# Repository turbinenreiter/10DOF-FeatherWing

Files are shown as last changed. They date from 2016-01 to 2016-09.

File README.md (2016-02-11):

# 10DOF-FeatherWing

This is a daughter-board for Adafruits Feather boards.  

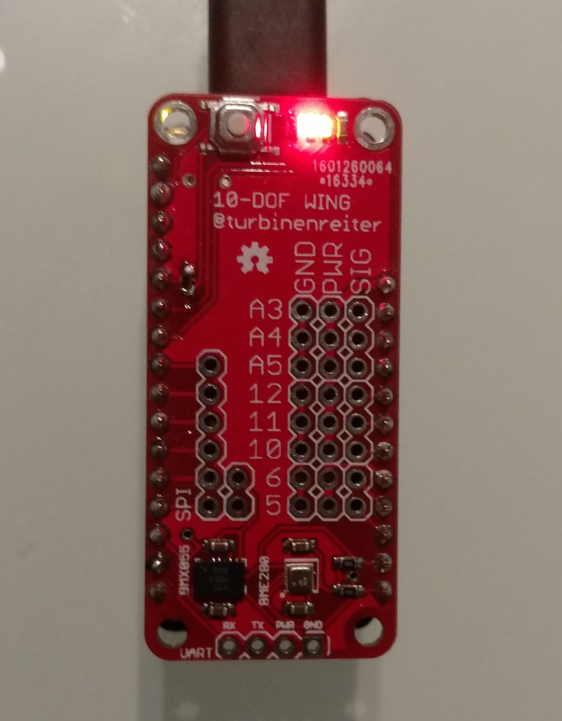
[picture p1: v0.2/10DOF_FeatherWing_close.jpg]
10DOF-FeatherWing


It features:
  * 3-axis accelerometer
  * 3-axis gyroscope
  * 3-axis magnetometer
  * temperature sensor
  * pressure sensor
  * humidity sensor
  * 8 servo headers (PWR from BAT)
  * SPI header
  * UART header
  * one green and one red LED
  * one switch
  * GPIO#9 (A7) is connected to BAT to measure it's voltage

The board has been produced and tested.
  * all sensors work
  * red LED works
  * green LED is on when connected to USB, but not battery - no idea why

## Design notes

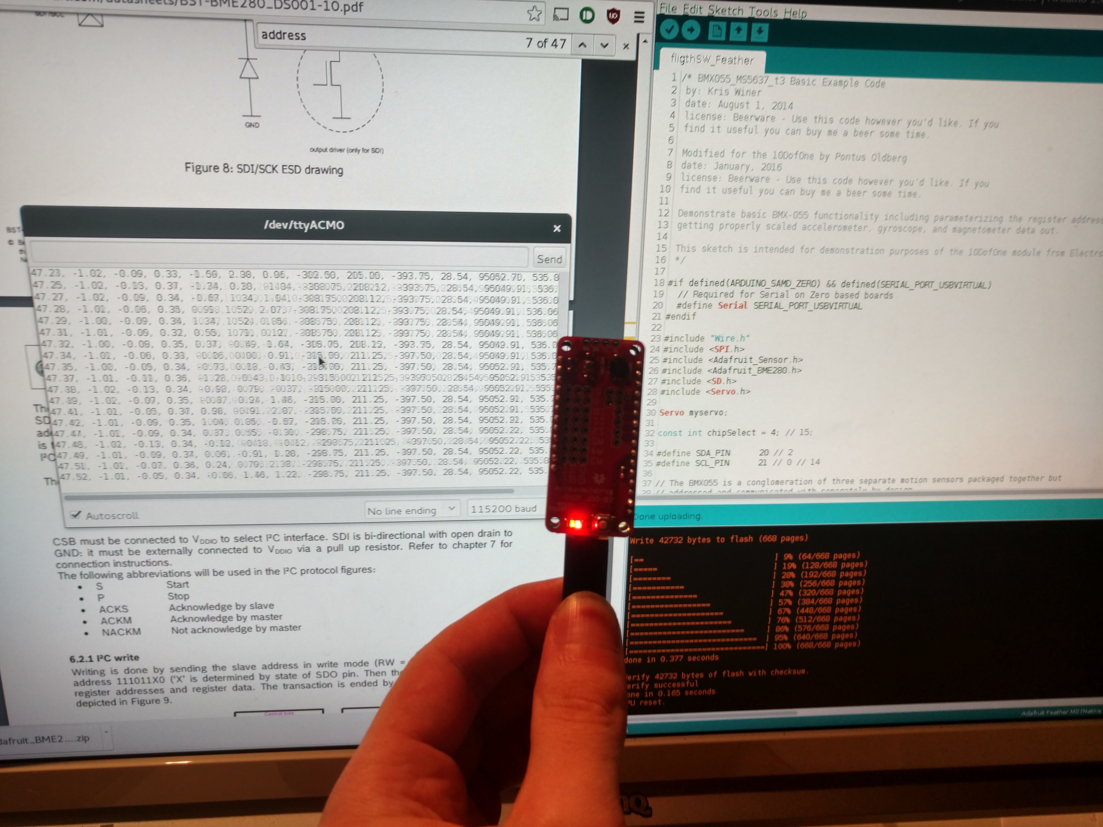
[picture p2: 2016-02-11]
v0.2/10DOF_FeatherWing_running.jpg

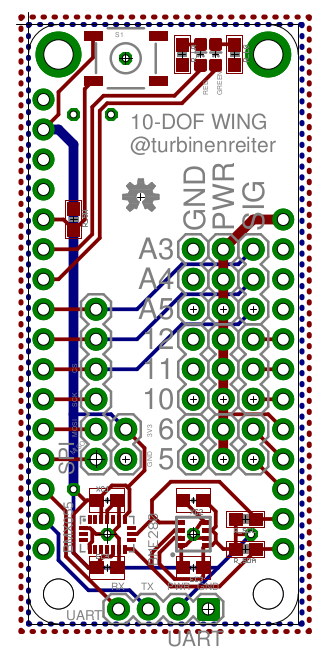
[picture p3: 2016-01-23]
v0.2/10DOF_FeatherWing_brd.png

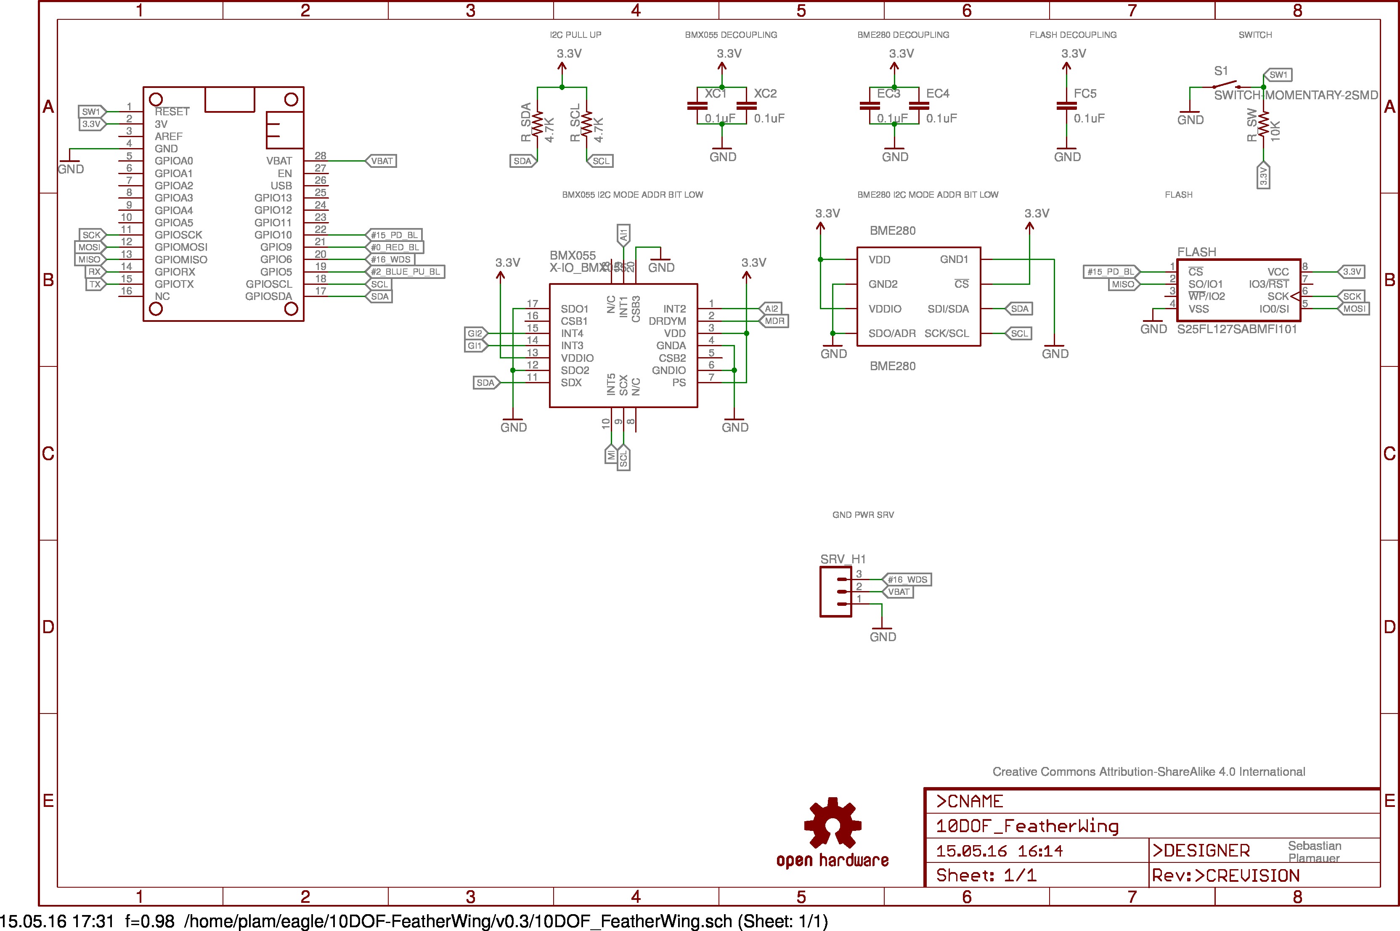
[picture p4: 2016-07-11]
v0.4SENSE/sch.jpg

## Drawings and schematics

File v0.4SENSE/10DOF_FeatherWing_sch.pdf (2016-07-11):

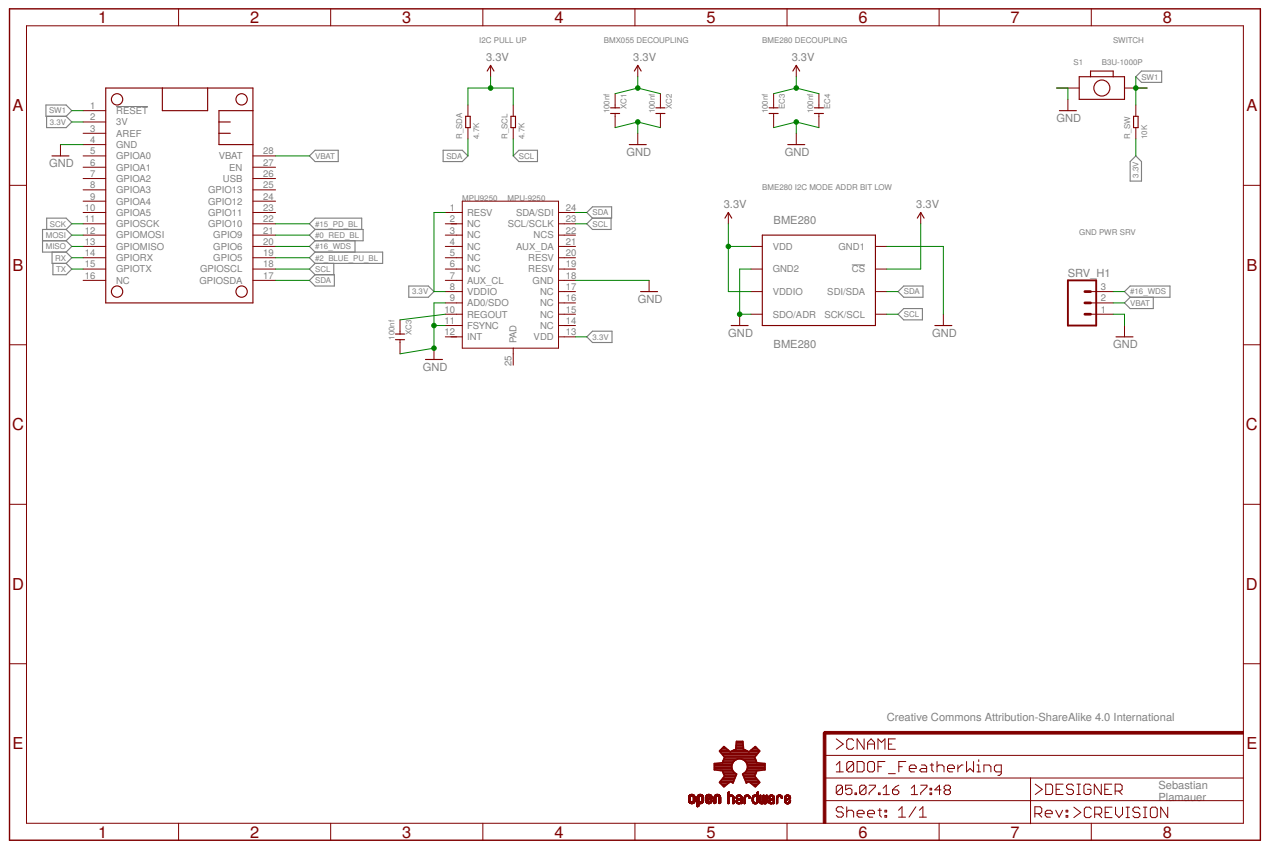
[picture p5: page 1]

BME280 I2C MODE ADDR BIT LOW

Creative Commons Attribution-ShareAlike 4.0 International

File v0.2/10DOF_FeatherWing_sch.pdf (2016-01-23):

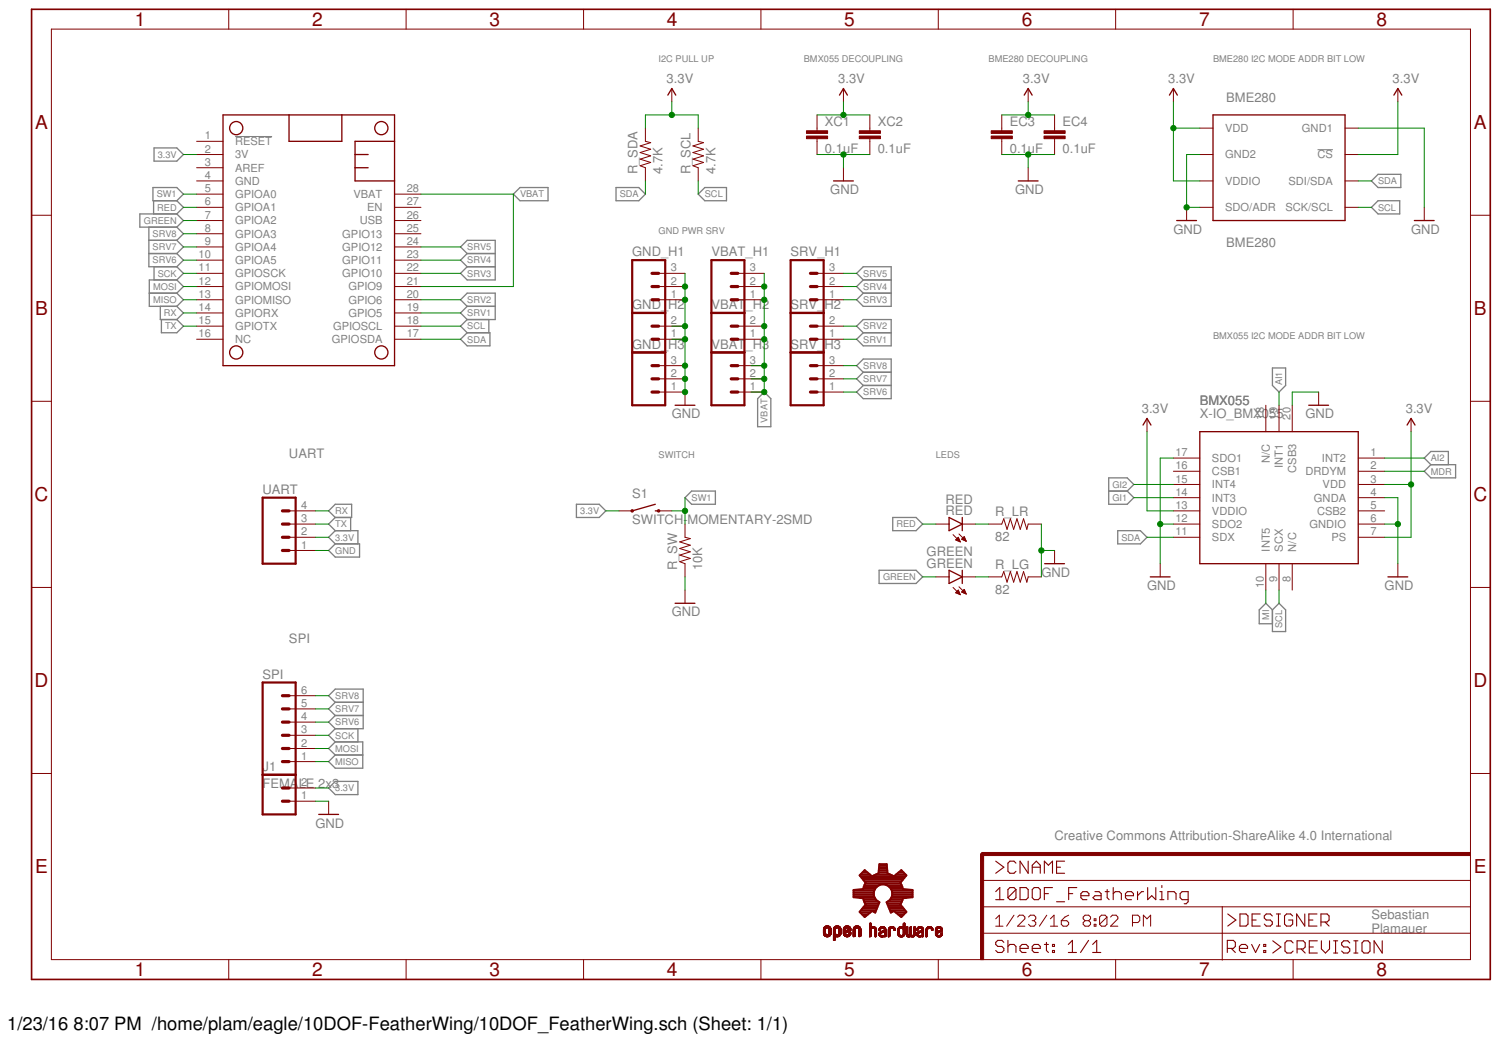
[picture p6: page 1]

BMX055 I2C MODE ADDR BIT LOW

Creative Commons Attribution-ShareAlike 4.0 International

1/23/16 8:07 PM /home/plam/eagle/10DOF-FeatherWing/10DOF_FeatherWing.sch (Sheet: 1/1)

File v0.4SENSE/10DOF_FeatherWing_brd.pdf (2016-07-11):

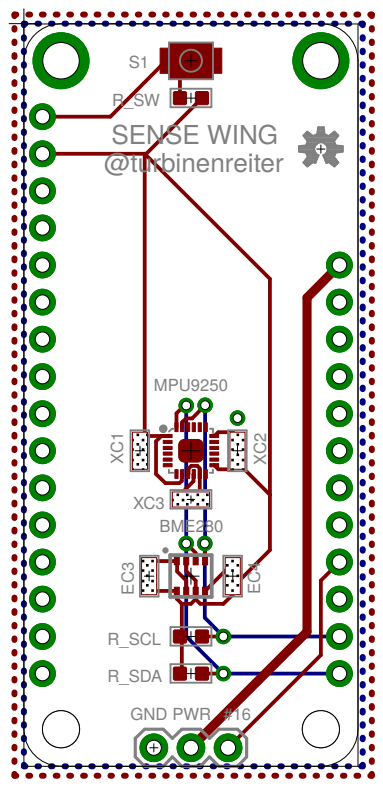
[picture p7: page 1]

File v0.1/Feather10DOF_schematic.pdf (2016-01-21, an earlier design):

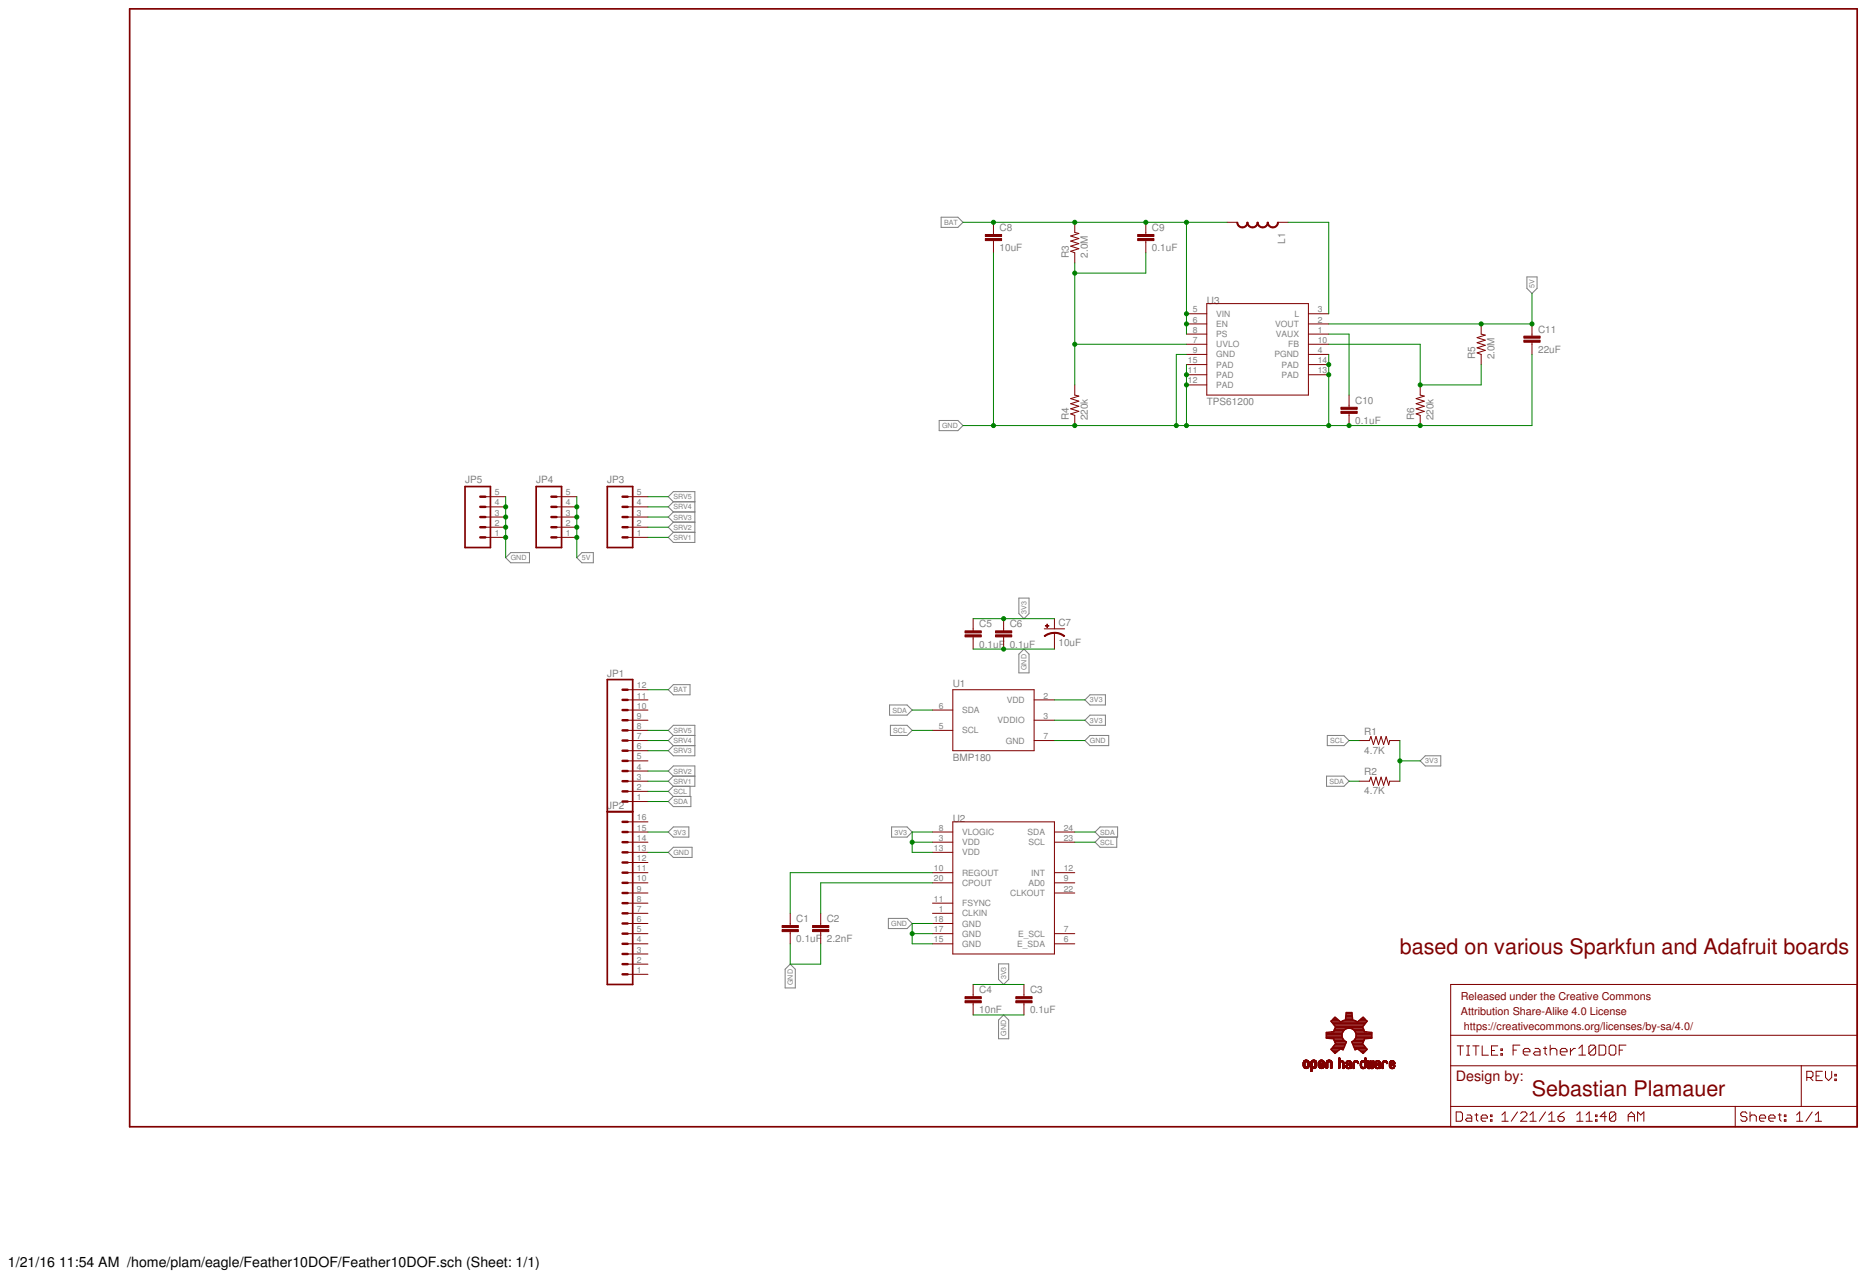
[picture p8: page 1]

based on various Sparkfun and Adafruit boards

Released under the Creative Commons Attribution Share-Alike 4.0 License

https://creativecommons.org/licenses/by-sa/4.0/

1/21/16 11:54 AM /home/plam/eagle/Feather10DOF/Feather10DOF.sch (Sheet: 1/1)

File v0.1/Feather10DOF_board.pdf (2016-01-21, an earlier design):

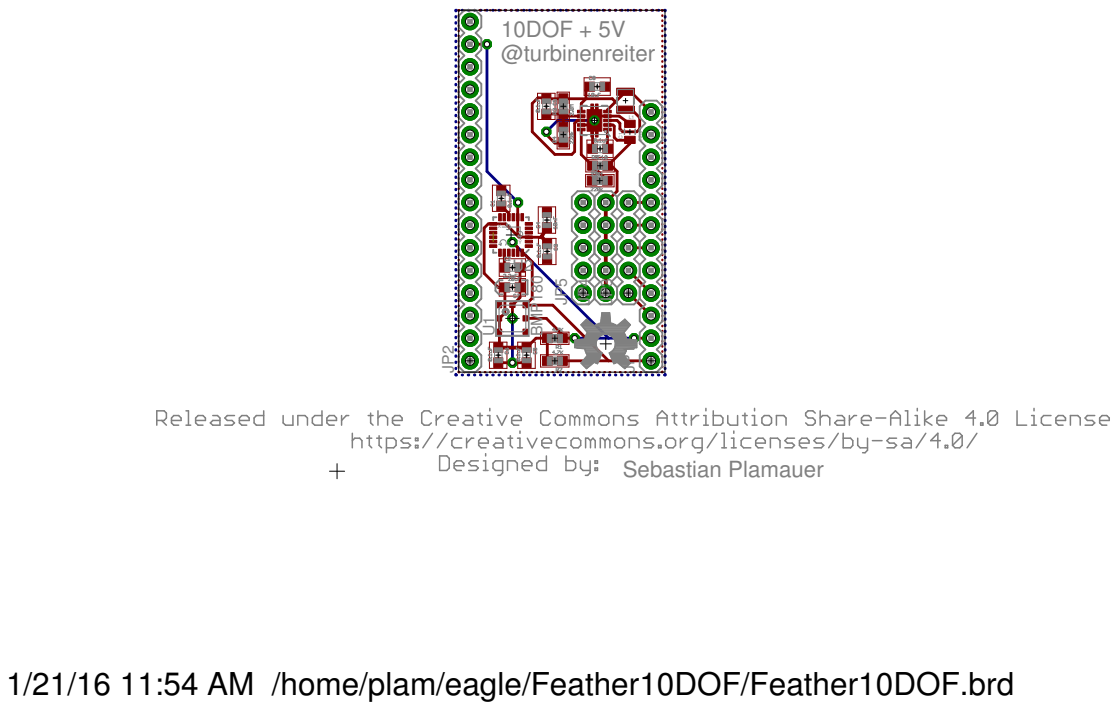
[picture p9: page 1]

1/21/16 11:54 AM /home/plam/eagle/Feather10DOF/Feather10DOF.brd

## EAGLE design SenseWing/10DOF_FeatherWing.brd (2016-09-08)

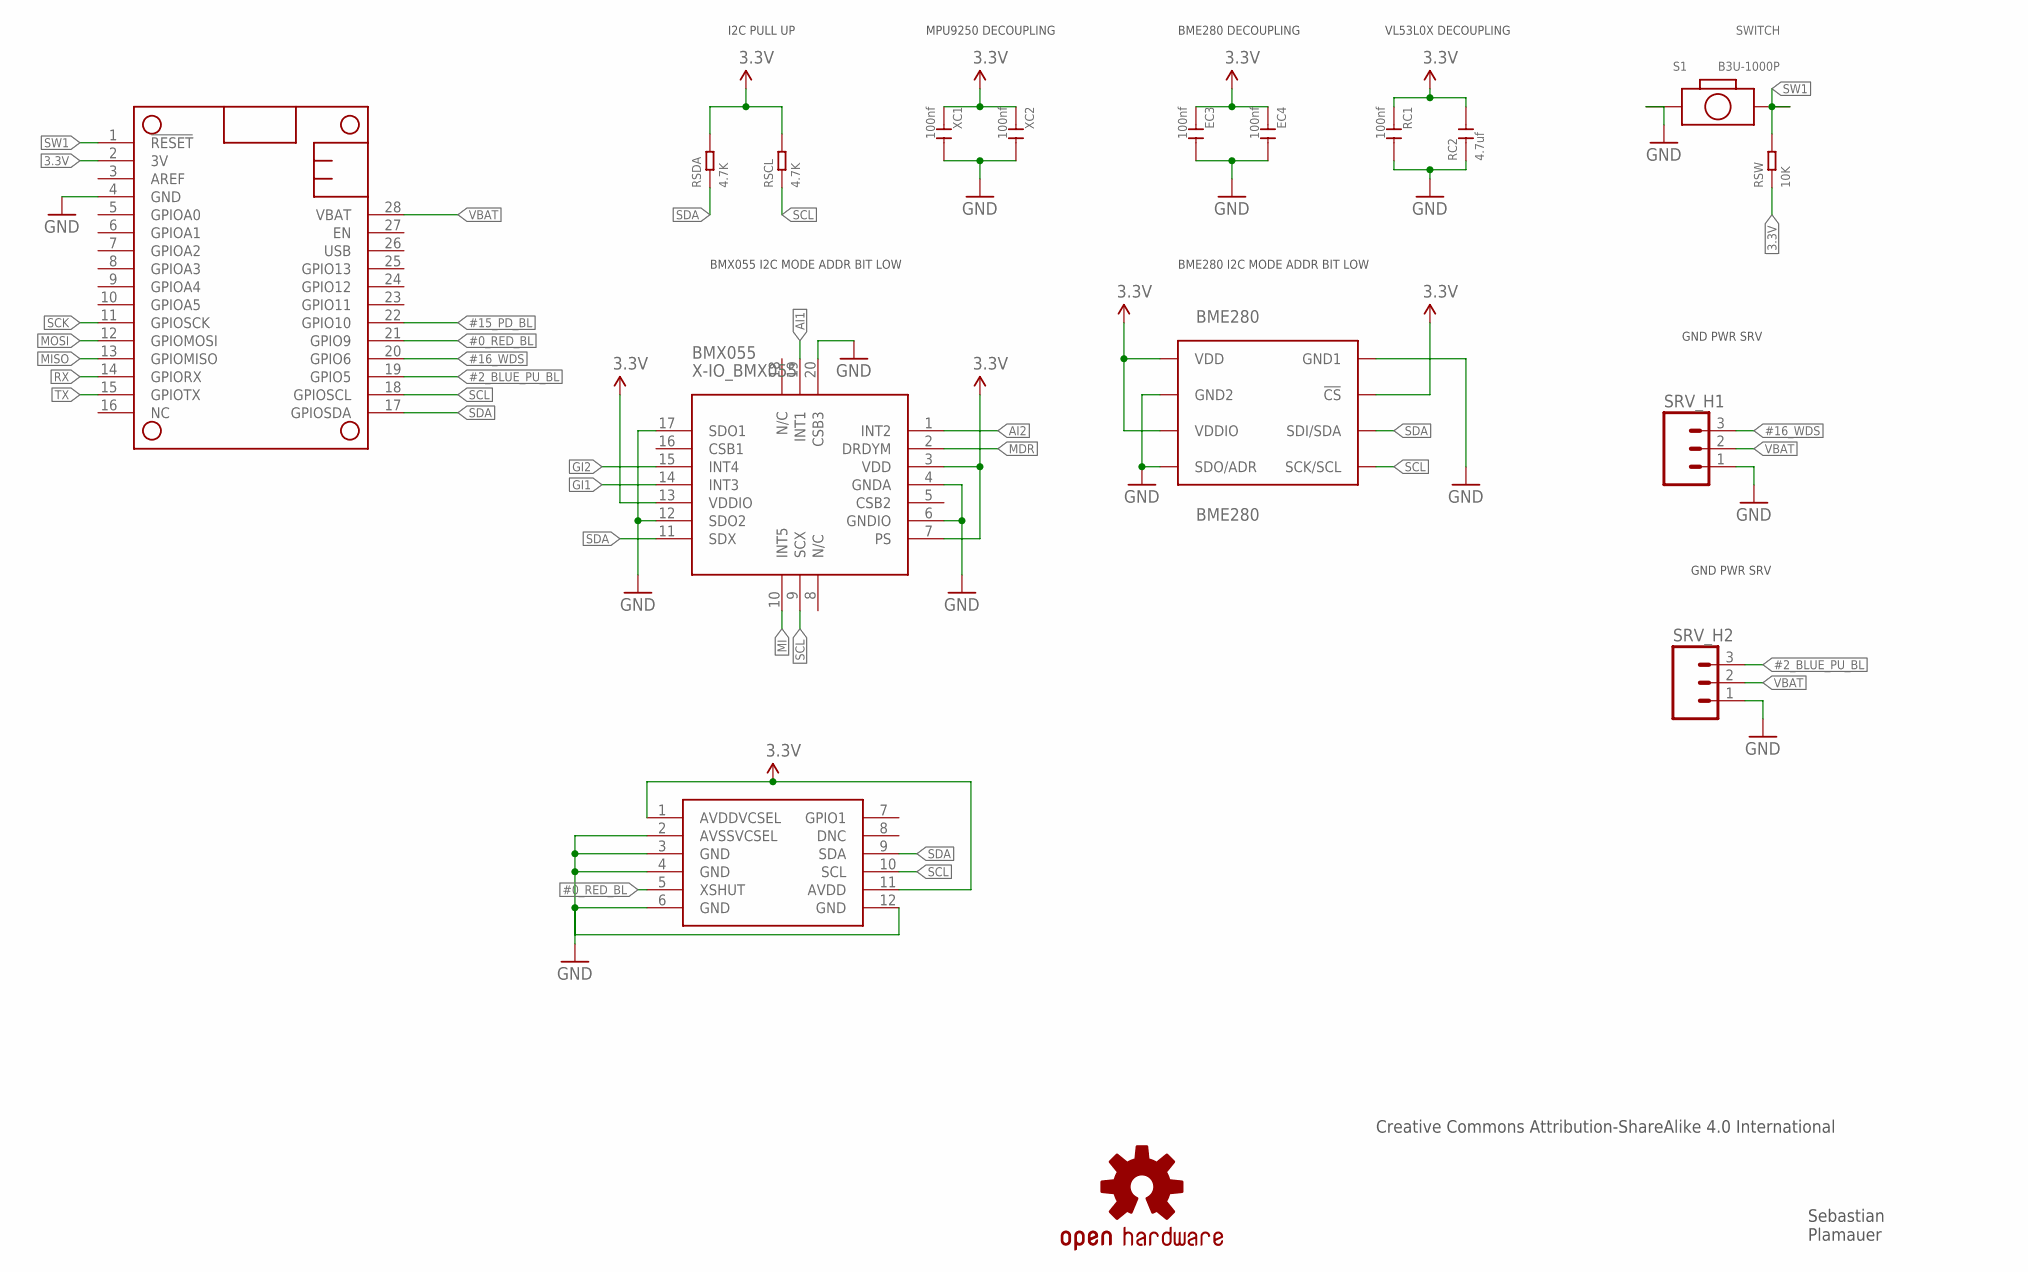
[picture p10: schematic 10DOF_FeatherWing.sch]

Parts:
BME280: BME280; BME280COMPONENTLIBRARY_BME280_LGA
BMX055: X-IO_BMX055
EC3, EC4: 100nf; C0603
LOGO1: OSHW-LOGOS; OSHW-LOGO-S
MS1: FEATHERWING
RC1: 100nf; C0603
RC2: 4.7uf; C0603
RSCL: 4.7K; R0603
RSDA: 4.7K; R0603
RSW: 10K; R0603
S1: B3U-1000P; SW2-SMD-3.0X2.5X1.2+0.4MM
SRV_H1, SRV_H2: M03PTH; 1X03
U$1: VL53L0X
XC1, XC2: 100nf; C0603

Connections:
3.3V: BME280.P$2 (!CS), BME280.P$6 (VDDIO), BME280.P$8 (VDD), BMX055.3 (VDD), BMX055.7 (PS), BMX055.13 (VDDIO), EC3.1, EC4.1, MS1.2 (3V), RC1.1, RC2.2, RSCL.2, RSDA.2, RSW.1, U$1.1 (AVDDVCSEL), U$1.11 (AVDD), XC1.1, XC2.1
#0_RED_BL: MS1.21 (GPIO9), U$1.5 (XSHUT)
#2_BLUE_PU_BL: MS1.19 (GPIO5), SRV_H2.3
#15_PD_BL: MS1.22 (GPIO10)
#16_WDS: MS1.20 (GPIO6), SRV_H1.3
AI1: BMX055.19 (INT1)
AI2: BMX055.1 (INT2)
GI1: BMX055.14 (INT3)
GI2: BMX055.15 (INT4)
GND: BME280.P$1 (GND1), BME280.P$5 (SDO/ADR), BME280.P$7 (GND2), BMX055.4 (GNDA), BMX055.6 (GNDIO), BMX055.12 (SDO2), BMX055.17 (SDO1), BMX055.20 (CSB3), EC3.2, EC4.2, MS1.4 (GND), RC1.2, RC2.1, S1.1, SRV_H1.1, SRV_H2.1, U$1.2 (AVSSVCSEL), U$1.3 (GND), U$1.4 (GND), U$1.6 (GND), U$1.12 (GND), XC1.2, XC2.2
MDR: BMX055.2 (DRDYM)
MI: BMX055.10 (INT5)
MISO: MS1.13 (GPIOMISO)
MOSI: MS1.12 (GPIOMOSI)
RX: MS1.14 (GPIORX)
SCK: MS1.11 (GPIOSCK)
SCL: BME280.P$4 (SCK/SCL), BMX055.9 (SCX), MS1.18 (GPIOSCL), RSCL.1, U$1.10 (SCL)
SDA: BME280.P$3 (SDI/SDA), BMX055.11 (SDX), MS1.17 (GPIOSDA), RSDA.1, U$1.9 (SDA)
SW1: MS1.1 (!RESET), RSW.2, S1.2
TX: MS1.15 (GPIOTX)
VBAT: MS1.28 (VBAT), SRV_H1.2, SRV_H2.2

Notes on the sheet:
I2C PULL UP
MPU9250 DECOUPLING
BME280 DECOUPLING
BME280 I2C MODE ADDR BIT LOW
GND PWR SRV
SWITCH
Sebastian Plamauer
Creative Commons Attribution-ShareAlike 4.0 International
VL53L0X DECOUPLING
BMX055 I2C MODE ADDR BIT LOW

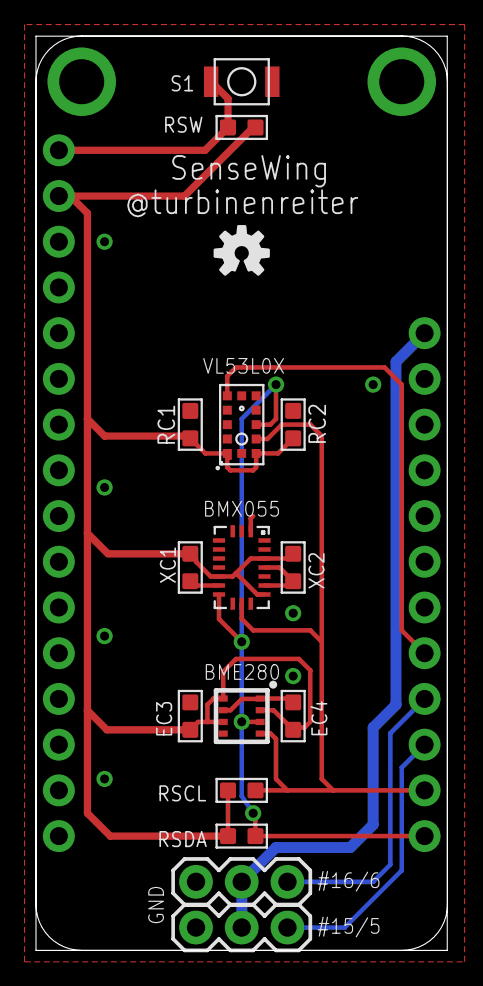
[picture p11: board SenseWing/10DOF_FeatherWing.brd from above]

Board: 2 copper layers, 22.9 x 50.8 mm, 17 parts (0 on the bottom side), 9 nets.

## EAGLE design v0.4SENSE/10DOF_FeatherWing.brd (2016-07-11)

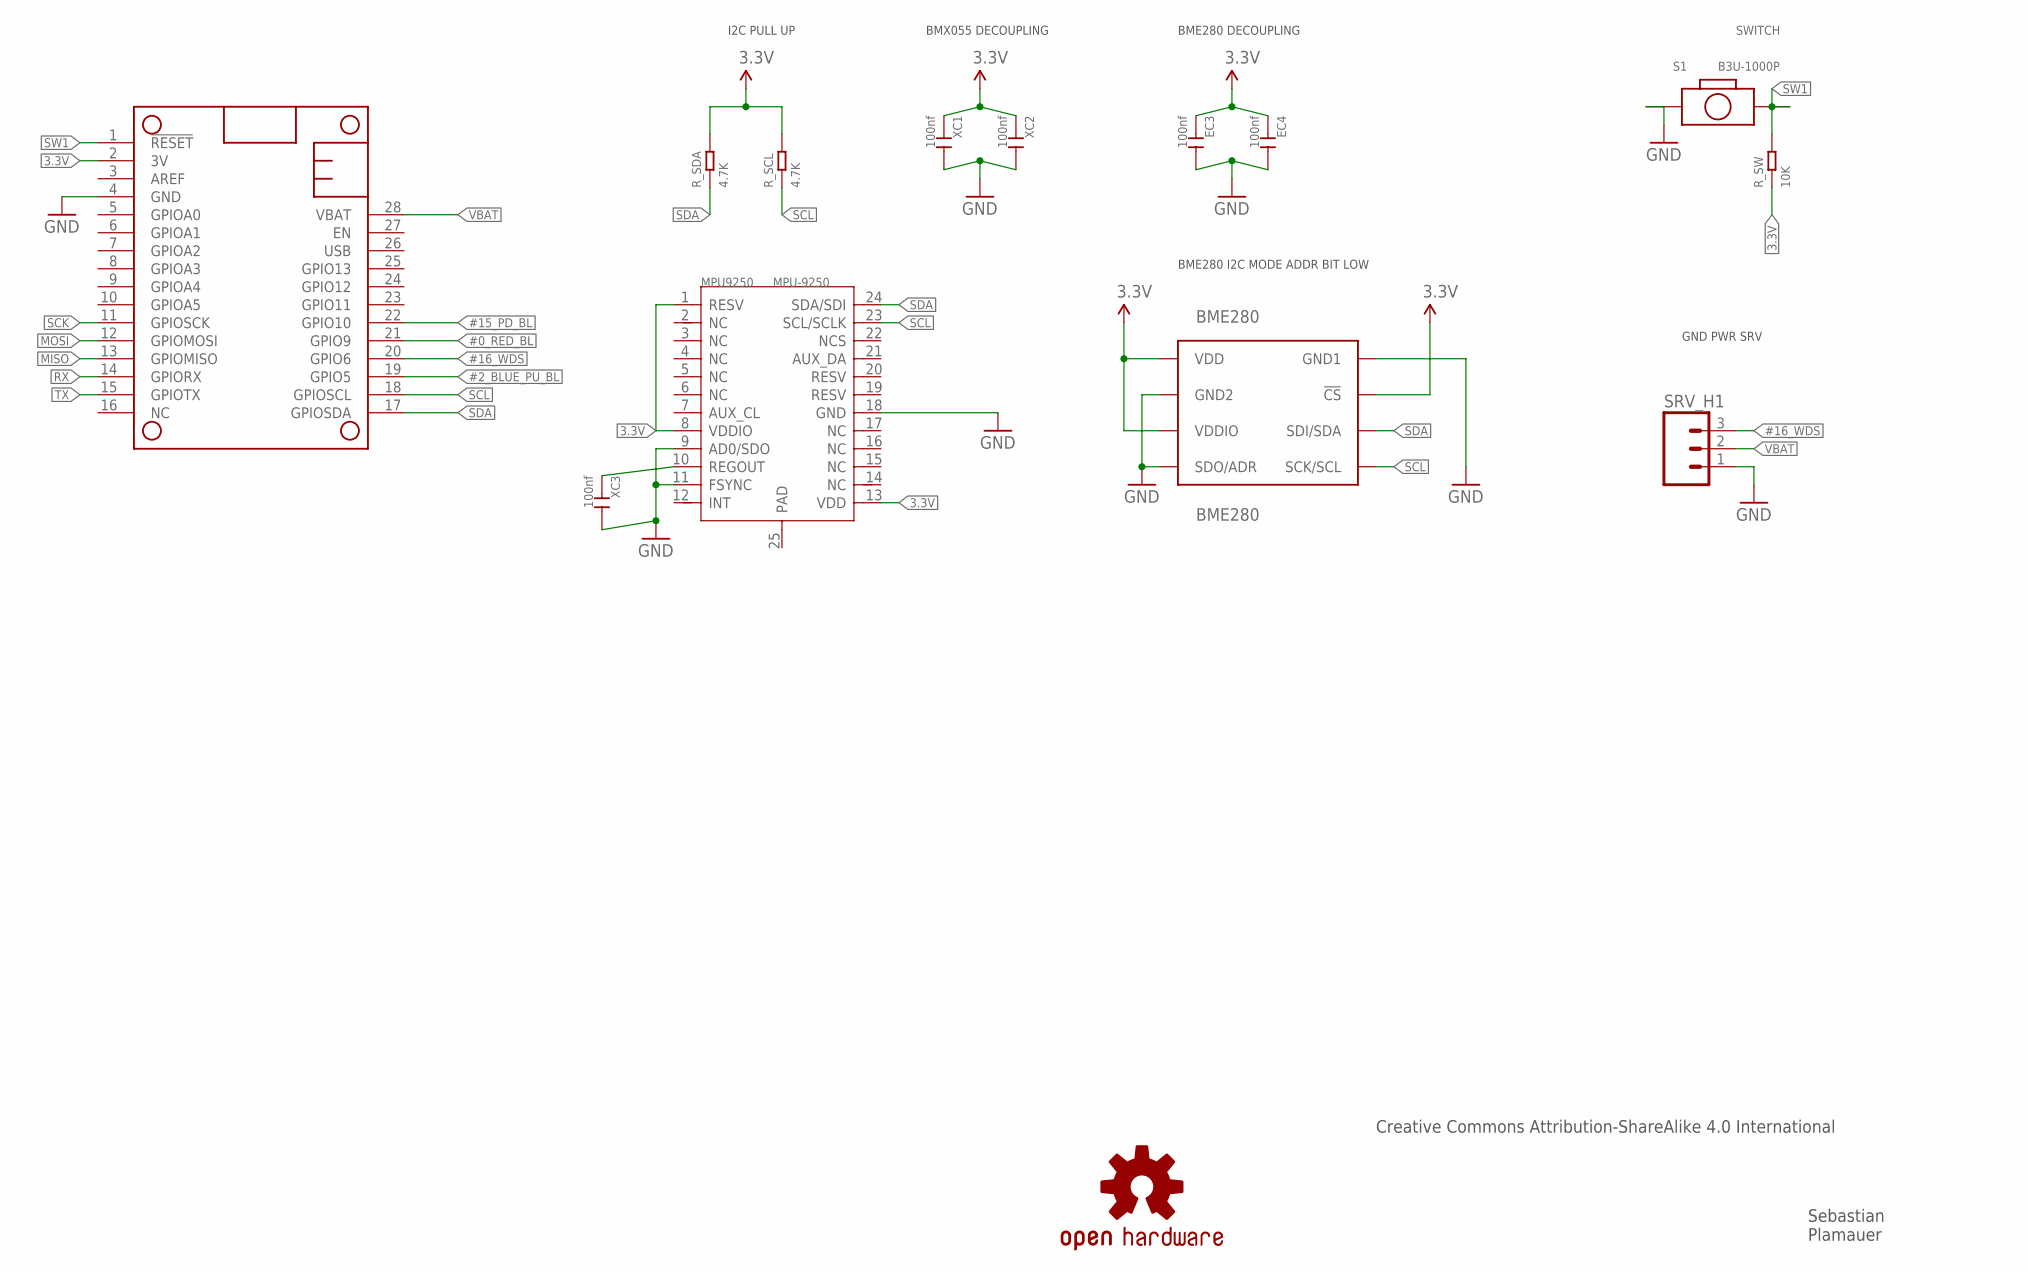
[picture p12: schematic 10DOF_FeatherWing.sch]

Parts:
BME280: BME280; BME280COMPONENTLIBRARY_BME280_LGA
EC3, EC4: 100nf; C0603
LOGO1: OSHW-LOGOS; OSHW-LOGO-S
MPU9250: MPU-9250; QFN24G-0.4-3X3MM
MS1: FEATHERWING
R_SCL: 4.7K; R0603
R_SDA: 4.7K; R0603
R_SW: 10K; R0603
S1: B3U-1000P; SW2-SMD-3.0X2.5X1.2+0.4MM
SRV_H1: M03PTH; 1X03
XC1, XC2, XC3: 100nf; C0603

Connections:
3.3V: BME280.P$2 (!CS), BME280.P$6 (VDDIO), BME280.P$8 (VDD), EC3.1, EC4.1, MPU9250.1 (RESV), MPU9250.8 (VDDIO), MPU9250.13 (VDD), MS1.2 (3V), R_SCL.2, R_SDA.2, R_SW.1, XC1.1, XC2.1
#0_RED_BL: MS1.21 (GPIO9)
#2_BLUE_PU_BL: MS1.19 (GPIO5)
#15_PD_BL: MS1.22 (GPIO10)
#16_WDS: MS1.20 (GPIO6), SRV_H1.3
GND: BME280.P$1 (GND1), BME280.P$5 (SDO/ADR), BME280.P$7 (GND2), EC3.2, EC4.2, MPU9250.9 (AD0/SDO), MPU9250.11 (FSYNC), MPU9250.18 (GND), MS1.4 (GND), S1.1, SRV_H1.1, XC1.2, XC2.2, XC3.2
MISO: MS1.13 (GPIOMISO)
MOSI: MS1.12 (GPIOMOSI)
unnamed: MPU9250.10 (REGOUT), XC3.1
RX: MS1.14 (GPIORX)
SCK: MS1.11 (GPIOSCK)
SCL: BME280.P$4 (SCK/SCL), MPU9250.23 (SCL/SCLK), MS1.18 (GPIOSCL), R_SCL.1
SDA: BME280.P$3 (SDI/SDA), MPU9250.24 (SDA/SDI), MS1.17 (GPIOSDA), R_SDA.1
SW1: MS1.1 (!RESET), R_SW.2, S1.2
TX: MS1.15 (GPIOTX)
VBAT: MS1.28 (VBAT), SRV_H1.2

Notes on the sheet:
I2C PULL UP
BMX055 DECOUPLING
BME280 DECOUPLING
BME280 I2C MODE ADDR BIT LOW
GND PWR SRV
SWITCH
Sebastian Plamauer
Creative Commons Attribution-ShareAlike 4.0 International

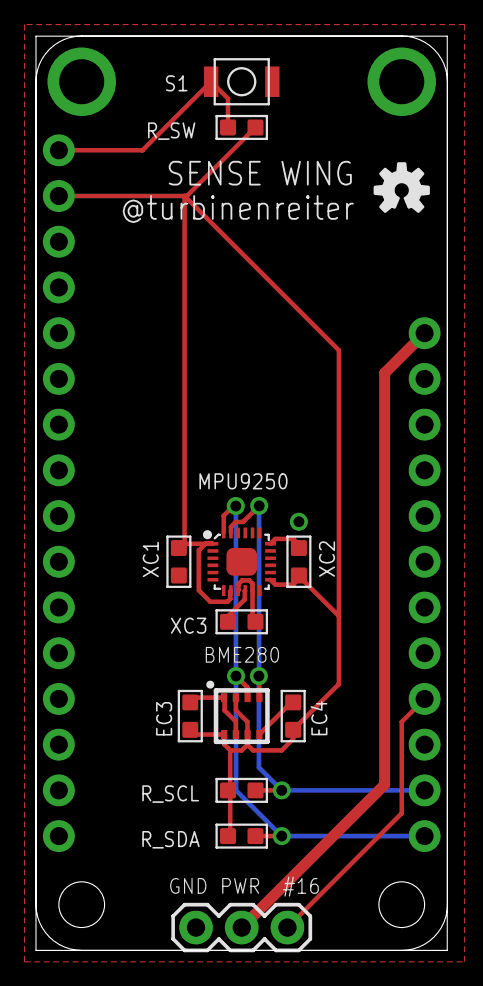
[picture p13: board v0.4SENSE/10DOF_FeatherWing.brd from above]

Board: 2 copper layers, 22.9 x 50.8 mm, 14 parts (0 on the bottom side), 8 nets.

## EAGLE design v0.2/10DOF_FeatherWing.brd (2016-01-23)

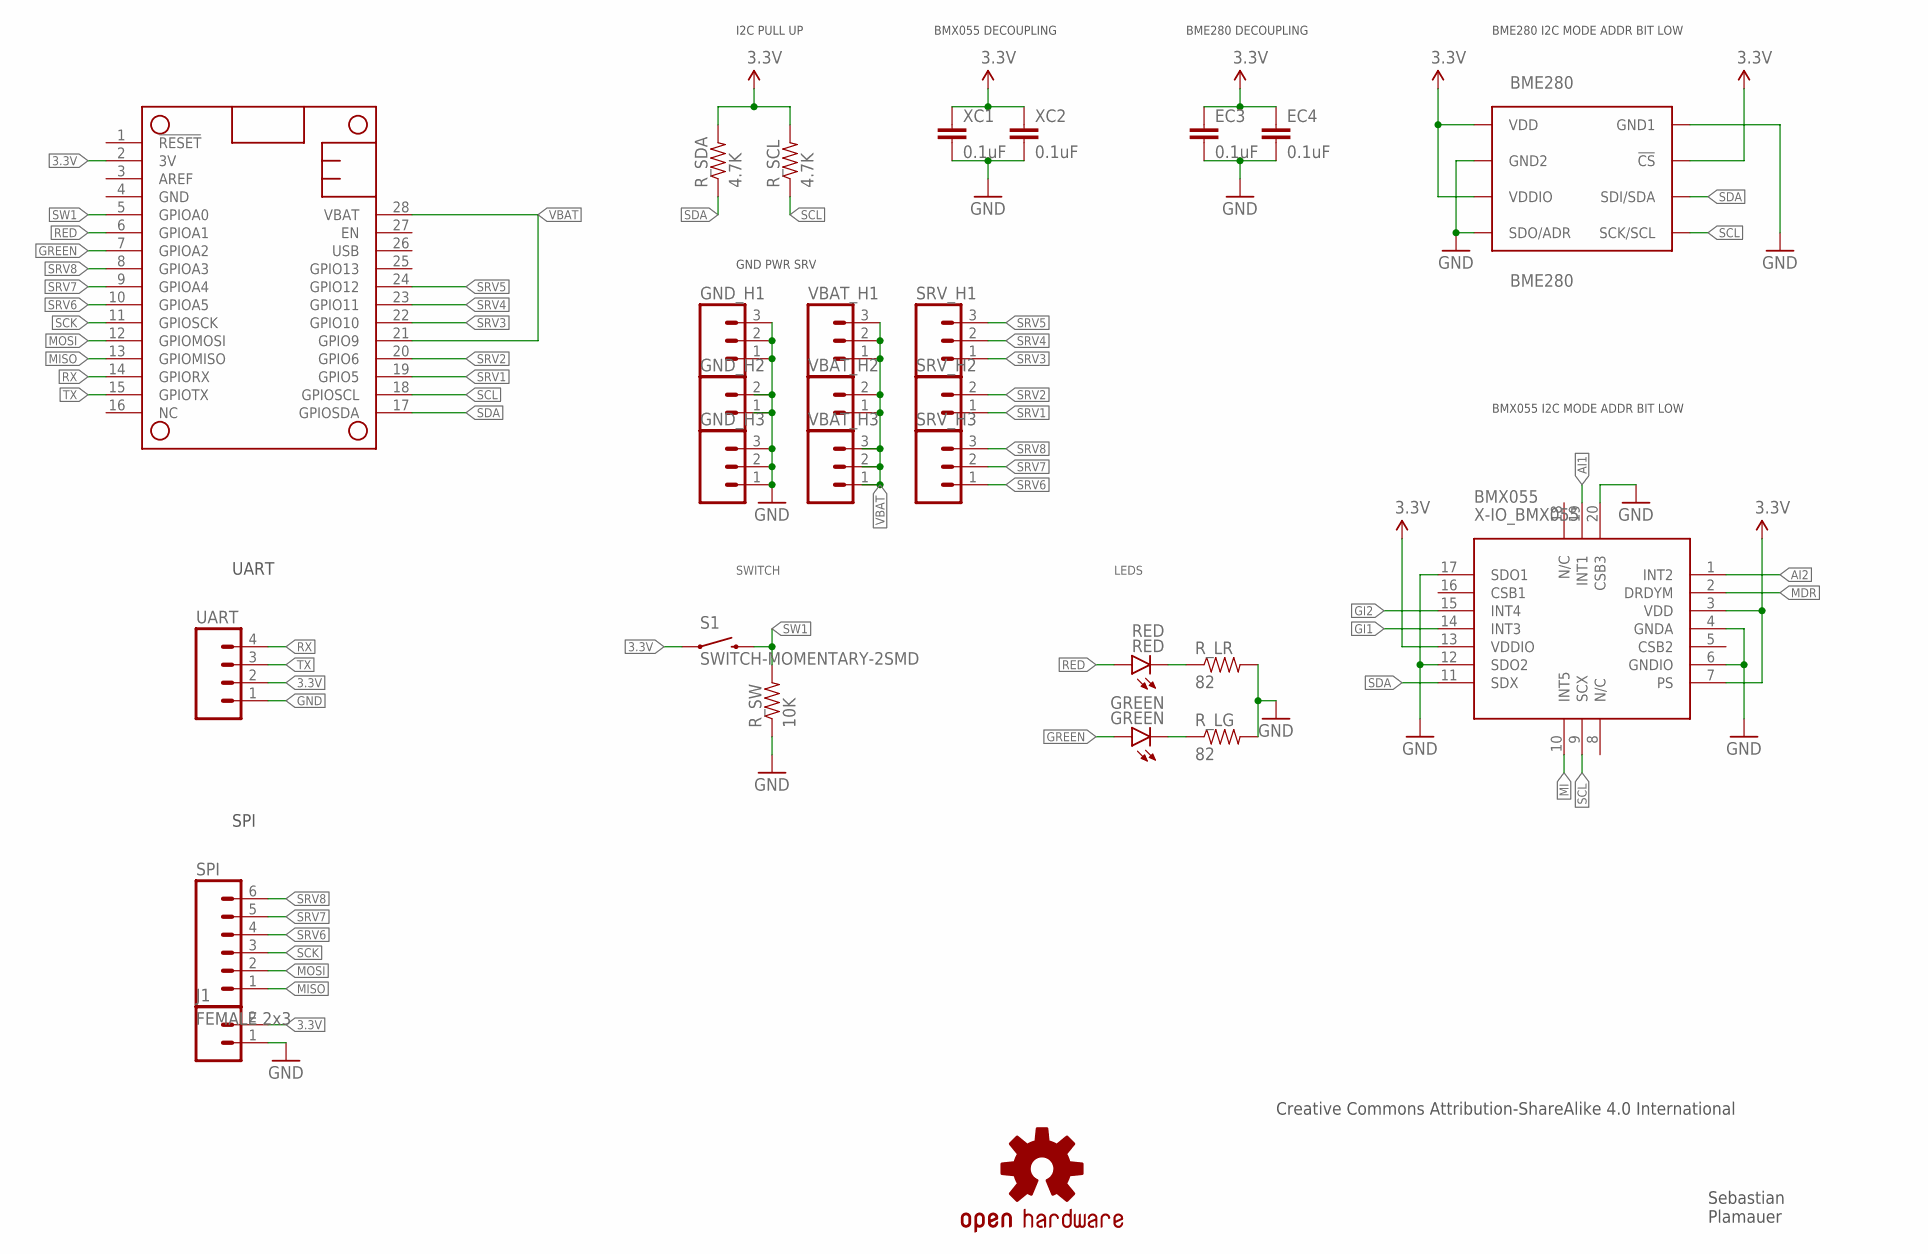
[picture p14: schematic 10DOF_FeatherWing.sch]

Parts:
BME280: BME280; BME280COMPONENTLIBRARY_BME280_LGA
BMX055: X-IO_BMX055
EC3, EC4: 0.1uF; 0603-CAP
GND_H1, GND_H3: M03PTH; 1X03
GND_H2: M02PTH; 1X02
GREEN: GREEN; LED-0603
J1: M02PTH; 1X02
LOGO1: OSHW-LOGOS; OSHW-LOGO-S
MS1: FEATHERWING
RED: RED; LED-0603
R_LG: 82; 0603-RES
R_LR: 82; 0603-RES
R_SCL: 4.7K; 0603-RES
R_SDA: 4.7K; 0603-RES
R_SW: 10K; 0603-RES
S1: SWITCH-MOMENTARY-2SMD; TACTILE-SWITCH-SMD
SPI: FEMALE 2x3; 1X06
SRV_H1, SRV_H3: M03PTH; 1X03
SRV_H2: M02PTH; 1X02
UART: M04PTH; 1X04
VBAT_H1, VBAT_H3: M03PTH; 1X03
VBAT_H2: M02PTH; 1X02
XC1, XC2: 0.1uF; 0603-CAP

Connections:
3.3V: BME280.P$2 (!CS), BME280.P$6 (VDDIO), BME280.P$8 (VDD), BMX055.3 (VDD), BMX055.7 (PS), BMX055.13 (VDDIO), EC3.1, EC4.1, J1.2, MS1.2 (3V), R_SCL.2, R_SDA.2, S1.1, UART.2, XC1.1, XC2.1
AI1: BMX055.19 (INT1)
AI2: BMX055.1 (INT2)
GI1: BMX055.14 (INT3)
GI2: BMX055.15 (INT4)
GND: BME280.P$1 (GND1), BME280.P$5 (SDO/ADR), BME280.P$7 (GND2), BMX055.4 (GNDA), BMX055.6 (GNDIO), BMX055.12 (SDO2), BMX055.17 (SDO1), BMX055.20 (CSB3), EC3.2, EC4.2, GND_H1.1, GND_H1.2, GND_H1.3, GND_H2.1, GND_H2.2, GND_H3.1, GND_H3.2, GND_H3.3, J1.1, MS1.4 (GND), R_LG.2, R_LR.2, R_SW.1, UART.1, XC1.2, XC2.2
GREEN: GREEN.A, MS1.7 (GPIOA2)
MDR: BMX055.2 (DRDYM)
MI: BMX055.10 (INT5)
MISO: MS1.13 (GPIOMISO), SPI.1
MOSI: MS1.12 (GPIOMOSI), SPI.2
unnamed: GREEN.C, R_LG.1
unnamed: RED.C, R_LR.1
RED: MS1.6 (GPIOA1), RED.A
RX: MS1.14 (GPIORX), UART.4
SCK: MS1.11 (GPIOSCK), SPI.3
SCL: BME280.P$4 (SCK/SCL), BMX055.9 (SCX), MS1.18 (GPIOSCL), R_SCL.1
SDA: BME280.P$3 (SDI/SDA), BMX055.11 (SDX), MS1.17 (GPIOSDA), R_SDA.1
SRV1: MS1.19 (GPIO5), SRV_H2.1
SRV2: MS1.20 (GPIO6), SRV_H2.2
SRV3: MS1.22 (GPIO10), SRV_H1.1
SRV4: MS1.23 (GPIO11), SRV_H1.2
SRV5: MS1.24 (GPIO12), SRV_H1.3
SRV6: MS1.10 (GPIOA5), SPI.4, SRV_H3.1
SRV7: MS1.9 (GPIOA4), SPI.5, SRV_H3.2
SRV8: MS1.8 (GPIOA3), SPI.6, SRV_H3.3
SW1: MS1.5 (GPIOA0), R_SW.2, S1.3 (2)
TX: MS1.15 (GPIOTX), UART.3
VBAT: MS1.21 (GPIO9), MS1.28 (VBAT), VBAT_H1.1, VBAT_H1.2, VBAT_H1.3, VBAT_H2.1, VBAT_H2.2, VBAT_H3.1, VBAT_H3.2, VBAT_H3.3

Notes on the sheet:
I2C PULL UP
BMX055 DECOUPLING
BME280 DECOUPLING
BME280 I2C MODE ADDR BIT LOW
BMX055 I2C MODE ADDR BIT LOW
GND PWR SRV
SWITCH
LEDS
UART
Sebastian Plamauer
Creative Commons Attribution-ShareAlike 4.0 International
SPI

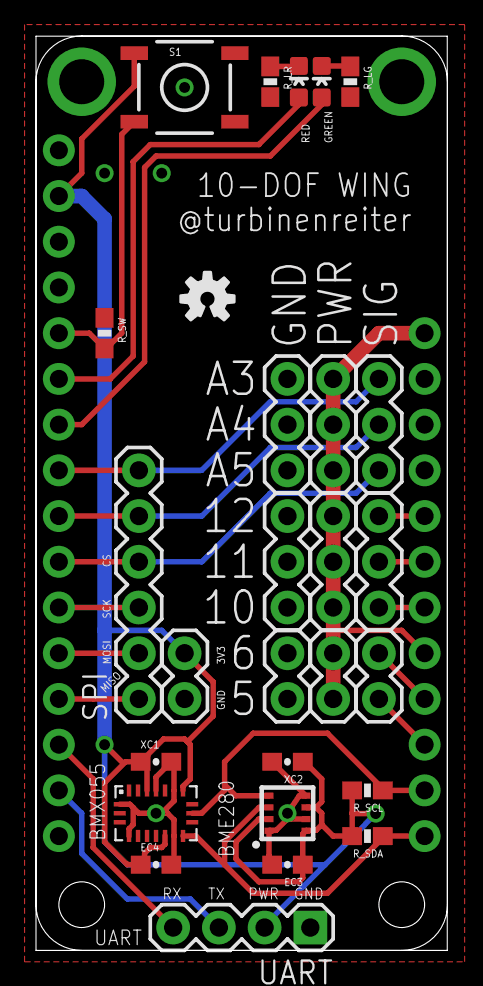
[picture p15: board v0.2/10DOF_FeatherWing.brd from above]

Board: 2 copper layers, 22.9 x 50.8 mm, 28 parts (0 on the bottom side), 23 nets.

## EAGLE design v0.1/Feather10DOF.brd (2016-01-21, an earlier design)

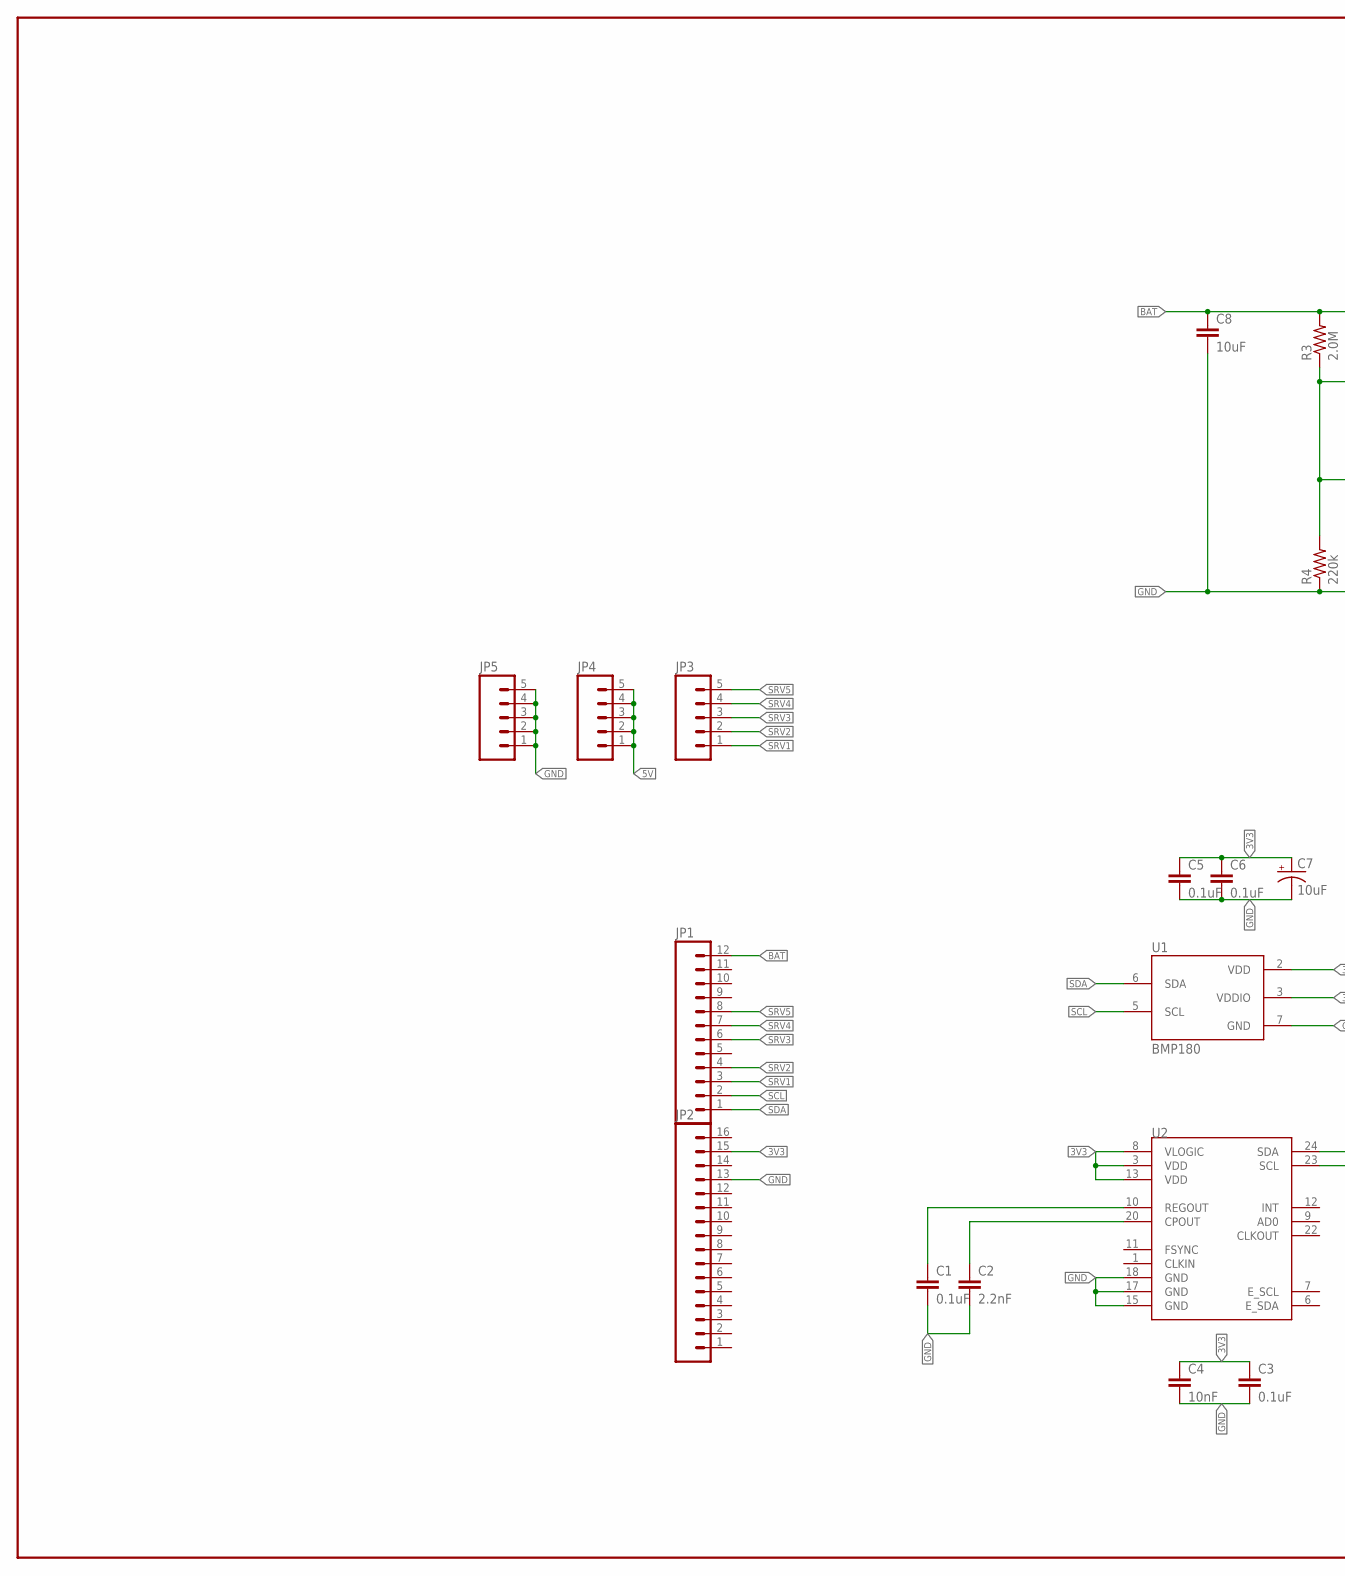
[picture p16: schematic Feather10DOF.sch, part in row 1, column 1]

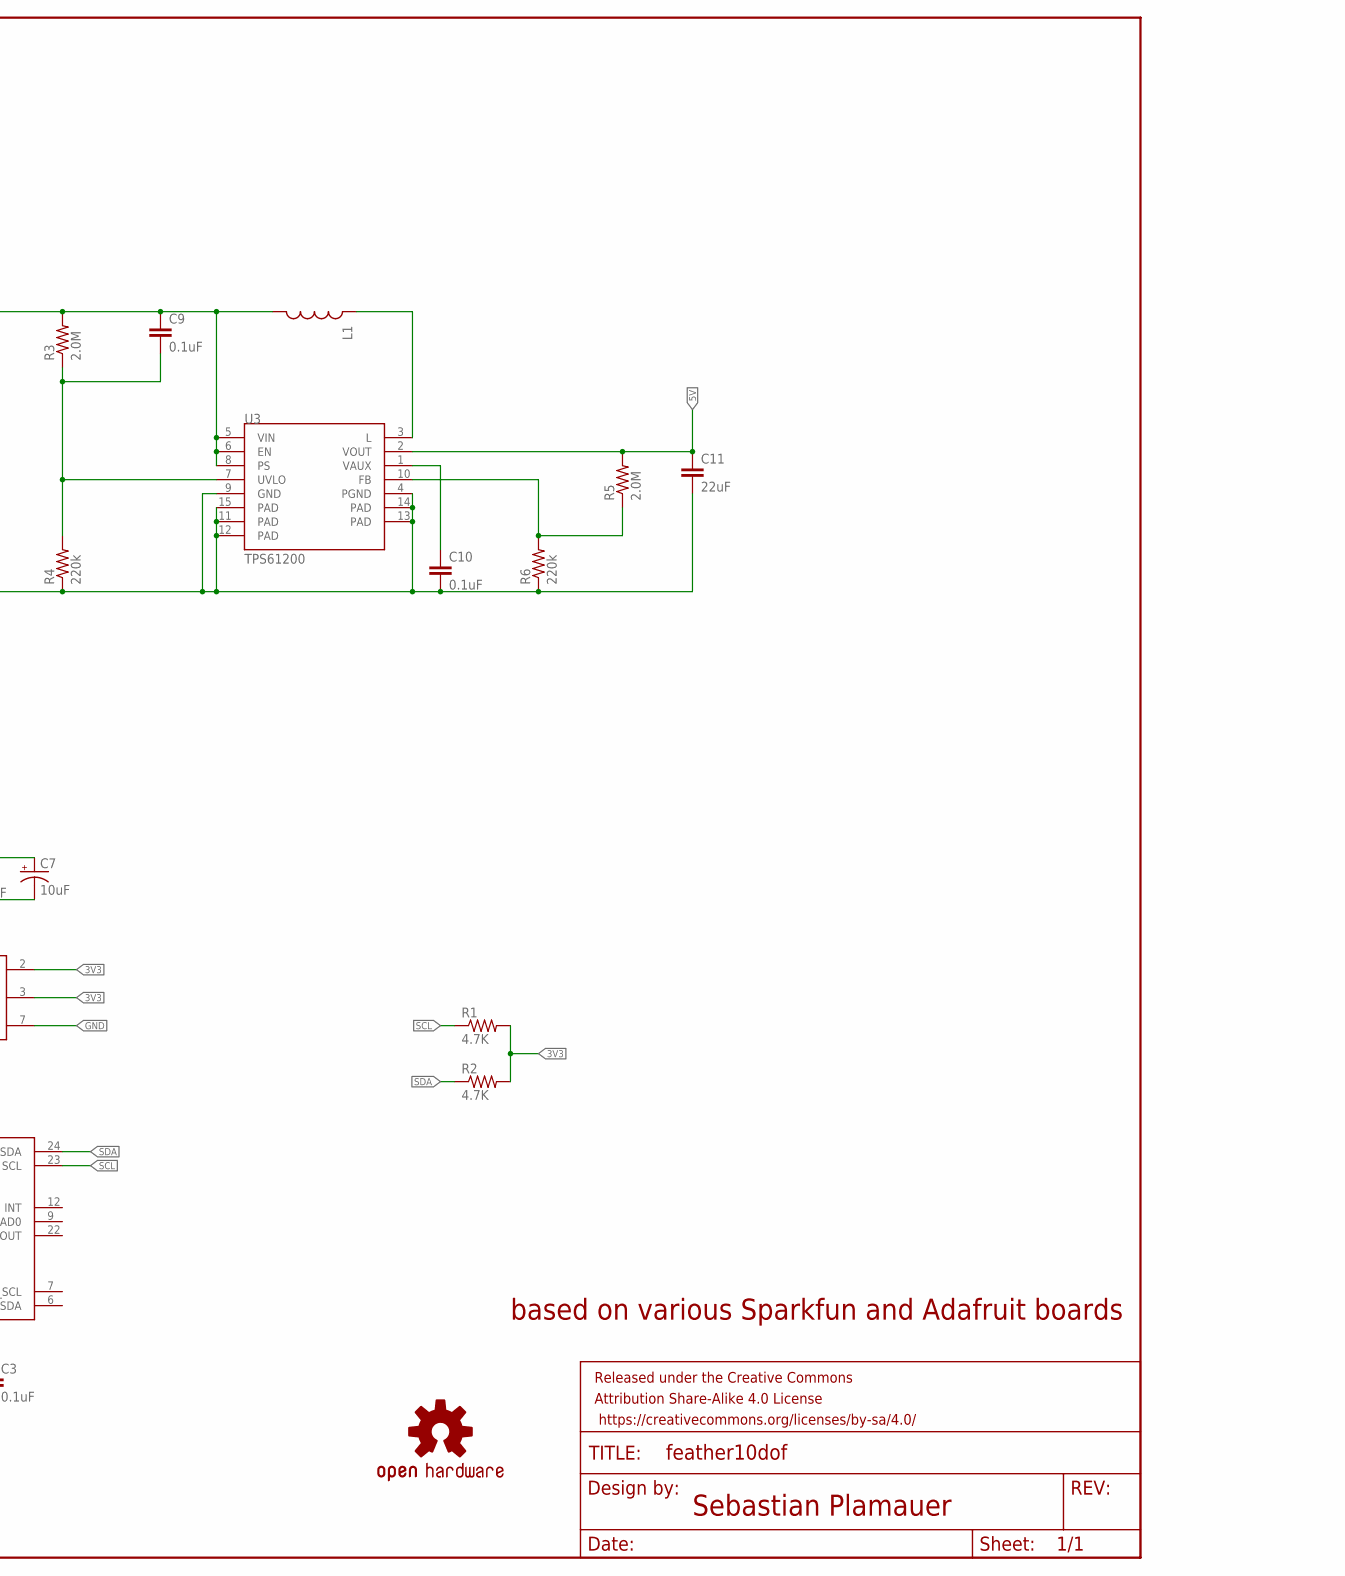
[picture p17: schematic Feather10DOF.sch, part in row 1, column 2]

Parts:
C1, C3, C5, C6, C9, C10: 0.1uF; 0603-CAP
C2: 2.2nF; 0603-CAP
C4: 10nF; 0603-CAP
C7: 10uF; 0603-POL
C8: 10uF; 0603-CAP
C11: 22uF; 0805
FRAME1: FRAME-LEDGER; CREATIVE_COMMONS
JP1: M12PTH; 1X12
JP2: M16PTH; 1X16
JP3, JP4, JP5: M05PTH; 1X05
L1: INDUCTOR1007; 1007
LOGO1: OSHW-LOGOL; OSHW-LOGO-L
R1, R2: 4.7K; 0603-RES
R3, R5: 2.0M; 0603-RES
R4, R6: 220k; 0603-RES
U1: BMP180
U2: MPU-9150QFN-24-NP; QFN-24-NP
U3: TPS61200; QFN-10_PAD

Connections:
3V3: C3.1, C4.1, C5.1, C6.1, C7.A (+), JP2.15, R1.2, R2.2, U1.2 (VDD), U1.3 (VDDIO), U2.3 (VDD), U2.8 (VLOGIC), U2.13 (VDD)
5V: C11.1, JP4.1, JP4.2, JP4.3, JP4.4, JP4.5, R5.2, U3.2 (VOUT)
BAT: C8.1, C9.1, JP1.12, L1.2, R3.2, U3.5 (VIN), U3.6 (EN), U3.8 (PS)
GND: C1.2, C2.2, C3.2, C4.2, C5.2, C6.2, C7.K (-), C8.2, C10.2, C11.2, JP2.13, JP5.1, JP5.2, JP5.3, JP5.4, JP5.5, R4.1, R6.1, U1.7 (GND), U2.15 (GND), U2.17 (GND), U2.18 (GND), U3.4 (PGND), U3.9 (GND), U3.11 (PAD), U3.12 (PAD), U3.13 (PAD), U3.14 (PAD), U3.15 (PAD)
unnamed: C2.1, U2.20 (CPOUT)
unnamed: C1.1, U2.10 (REGOUT)
unnamed: R5.1, R6.2, U3.10 (FB)
unnamed: C9.2, R3.1, R4.2, U3.7 (UVLO)
unnamed: L1.1, U3.3 (L)
unnamed: C10.1, U3.1 (VAUX)
SCL: JP1.2, R1.1, U1.5 (SCL), U2.23 (SCL)
SDA: JP1.1, R2.1, U1.6 (SDA), U2.24 (SDA)
SRV1: JP1.3, JP3.1
SRV2: JP1.4, JP3.2
SRV3: JP1.6, JP3.3
SRV4: JP1.7, JP3.4
SRV5: JP1.8, JP3.5

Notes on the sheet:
Sebastian Plamauer
based on various Sparkfun and Adafruit boards

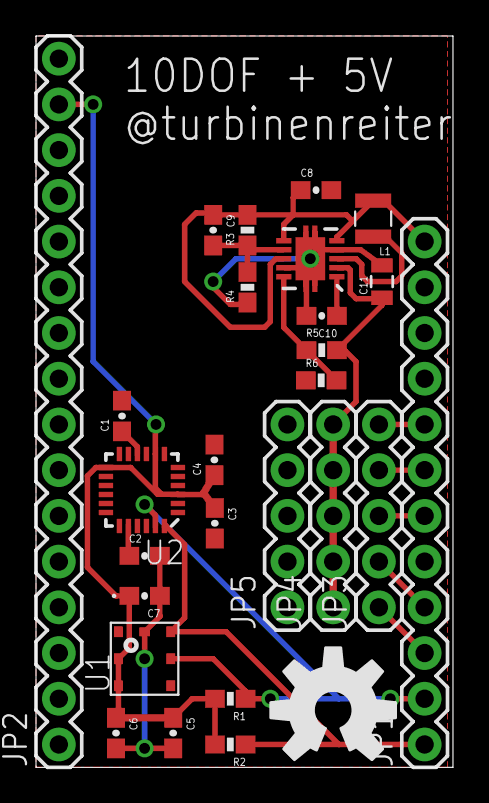
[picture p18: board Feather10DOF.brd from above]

Board: 2 copper layers, 23.2 x 40.6 mm, 28 parts (0 on the bottom side), 17 nets.

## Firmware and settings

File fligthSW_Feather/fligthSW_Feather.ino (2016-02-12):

/* flightSW_Feather
  including:
  BMX055_MS5637_t3 Basic Example Code
  by: Kris Winer
  date: August 1, 2014
  license: Beerware - Use this code however you'd like. If you
  find it useful you can buy me a beer some time.

  Modified for the 10DofOne by Pontus Oldberg
  date: January, 2016
  license: Beerware - Use this code however you'd like. If you
  find it useful you can buy me a beer some time.

  Modified for the 10-DOF WING for Adalooger M0 by Sebastian Plamauer
  date: February, 2016
  license: Beerware - Use this code however you'd like. If you
  find it useful you can buy me a beer some time.
*/

#if defined(ARDUINO_SAMD_ZERO) && defined(SERIAL_PORT_USBVIRTUAL)
#define Serial SERIAL_PORT_USBVIRTUAL
#endif

#include "BMX055.h"
#include "Wire.h"
#include <SPI.h>
#include <Adafruit_Sensor.h>
#include <Adafruit_BME280.h>
#include <SD.h>
#include <Servo.h>

#define DEBUG
#define LOG

Servo myservo;

const int chipSelect = 4;
const int myLed = 15; // red
const int ServoLed = 16; //green

float t, ax, ay, az, gx, gy, gz, mx, my, mz, T, p, alt; // variables to hold latest sensor data values
float out[] = {t, ax, ay, az, gx, gy, gz, mx, my, mz, T, p, alt};

int t0 = 0;
int para_flag = 0;

File dataFile;

Adafruit_BME280 baro; // on add 76 - change in lib

// BMX055 stuff
// Specify sensor full scale
uint8_t Gscale = GFS_2000DPS;       // set gyro full scale
uint8_t GODRBW = G_200Hz23Hz;      // set gyro ODR and bandwidth
uint8_t Ascale = AFS_16G;           // set accel full scale
uint8_t ACCBW  = 0x08 | ABW_63Hz;  // Choose bandwidth for accelerometer, need bit 3 = 1 to enable bandwidth choice in enum
uint8_t Mmode  = Regular;          // Choose magnetometer operation mode
uint8_t MODR   = MODR_10Hz;        // set magnetometer data rate
float aRes, gRes, mRes;            // scale resolutions per LSB for the sensors

// Parameters to hold BMX055 trim values
signed char   dig_x1;
signed char   dig_y1;
signed char   dig_x2;
signed char   dig_y2;
uint16_t      dig_z1;
int16_t       dig_z2;
int16_t       dig_z3;
int16_t       dig_z4;
unsigned char dig_xy1;
signed char   dig_xy2;
uint16_t      dig_xyz1;

// Pin definitions
// The BMX055 has three sensors, and two interrupt pins per device!
int intACC1   =  28;  // These are fixed on the BMX055 Mini Add-On for Teensy 3.1
int intACC2   =  29;
int intGYRO1  = 211;
int intGYRO2  = 210;
int intMAG1   = 212;
int intDRDYM  = 215;

// BMX055 variables
int16_t accelCount[3];  // Stores the 16-bit signed accelerometer sensor output
int16_t gyroCount[3];   // Stores the 16-bit signed gyro sensor output
int16_t magCount[3];    // Stores the 13/15-bit signed magnetometer sensor output
float gyroBias[3] = {0, 0, 0}, accelBias[3] = {0, 0, 0}, magBias[3] = {0, 0, 0};  // Bias corrections for gyro, accelerometer, mag
int16_t tempCount;            // temperature raw count output
float   temperature;          // Stores the BMX055 internal chip temperature in degrees Celsius
float SelfTest[6];            // holds results of gyro and accelerometer self test
int zerogcount = 0;

void setup()
{
  Wire.begin();

  Serial.begin(115200);
  Serial.println(F("\nStarting BMX055 tests !"));

  pinMode(ServoLed, OUTPUT);
  digitalWrite(ServoLed, LOW);

  pinMode(myLed, OUTPUT);
  digitalWrite(myLed, HIGH);
  delay(250);
  digitalWrite(myLed, LOW);
  delay(250);
  digitalWrite(myLed, HIGH);
  delay(250);
  digitalWrite(myLed, LOW);

  if (!SD.begin(chipSelect)) {
    Serial.println("Card failed, or not present");
    // don't do anything more:
    return;
  }
  Serial.println("card initialized.");

  byte c = readByte(BMX055_ACC_ADDRESS, BMX055_ACC_WHOAMI);  // Read ACC WHO_AM_I register for BMX055
  byte d = readByte(BMX055_GYRO_ADDRESS, BMX055_GYRO_WHOAMI);  // Read GYRO WHO_AM_I register for BMX055
  writeByte(BMX055_MAG_ADDRESS, BMX055_MAG_PWR_CNTL1, 0x01); // wake up magnetometer first thing
  delay(100);
  byte e = readByte(BMX055_MAG_ADDRESS, BMX055_MAG_WHOAMI);  // Read MAG WHO_AM_I register for BMX055

  if ((c == 0xFA) && (d == 0x0F) && (e == 0x32)) // WHO_AM_I should always be ACC = 0xFA, GYRO = 0x0F, MAG = 0x32
  {
    Serial.println("BMX055 is online...");

    initBMX055();
    // get sensor resolutions, only need to do this once
    getAres();
    getGres();
    // magnetometer resolution is 1 microTesla/16 counts or 1/1.6 milliGauss/count
    mRes = 1. / 1.6;
    trimBMX055();  // read the magnetometer calibration data

    fastcompaccelBMX055(accelBias);
    magcalBMX055(magBias);

  }
  else
  {
    Serial.print("Could not connect to BMX055: 0x");
    while (1) ; // Loop forever if communication doesn't happen
  }

  if (!baro.begin()) {
    Serial.println("Could not find a valid BME280 sensor, check wiring!");
    while (1);
  }

  File dataFile = SD.open("log.csv", FILE_WRITE);

  if (dataFile) {
    dataFile.println("t, ax, ay, az, gx, gy, gz, mx, my, mz, T, p, alt");
    dataFile.close();
  }
  // if the file isn't open, pop up an error:
  else {
    Serial.println("error opening log.csv");
    while (1);
  }

#ifndef DEBUG
  Serial.end();
#endif
  myservo.attach(5);
  myservo.write(90);
  delay(150);
  digitalWrite(myLed, HIGH);
}

void loop()
{
#ifdef LOG
  File dataFile = SD.open("log.csv", FILE_WRITE);
#endif
  t0 = millis();

  while (millis() < t0 + 1000) {

    t = millis() / 1000.0;

    readAccelData(accelCount);  // Read the x/y/z adc values
    // Now we'll calculate the accleration value into actual g's
    ax = (float)accelCount[0] * aRes + accelBias[0]; // get actual g value, this depends on scale being set
    ay = (float)accelCount[1] * aRes + accelBias[1];
    az = (float)accelCount[2] * aRes + accelBias[2];

    readGyroData(gyroCount);  // Read the x/y/z adc values
    // Calculate the gyro value into actual degrees per second
    gx = (float)gyroCount[0] * gRes; // get actual gyro value, this depends on scale being set
    gy = (float)gyroCount[1] * gRes;
    gz = (float)gyroCount[2] * gRes;

    readMagData(magCount);  // Read the x/y/z adc values
    // Calculate the magnetometer values in milliGauss
    // Temperature-compensated magnetic field is in 16 LSB/microTesla
    mx = (float)magCount[0] * mRes - magBias[0]; // get actual magnetometer value, this depends on scale being set
    my = (float)magCount[1] * mRes - magBias[1];
    mz = (float)magCount[2] * mRes - magBias[2];

    T = baro.readTemperature();
    p = baro.readPressure();
    alt = baro.readAltitude(1013.25);

    float out[] = {t, ax, ay, az, gx, gy, gz, mx, my, mz, T, p, alt};

    if (az < 0.1 && para_flag == 0 && zerogcount > 100) {
      myservo.write(45);              // tell servo to go to position in variable 'pos'
      para_flag = 1;
      digitalWrite(ServoLed, HIGH);
      delay(15);                       // waits 15ms for the servo to reach the position
    } else if (az < 0.1 && para_flag == 0) {
      zerogcount++;
    }

#ifdef DEBUG
    for (int i = 0; i < 13; i++) {
      Serial.print(out[i]);
      if (i < 12) {
        Serial.print(", ");
      }
    }
    Serial.println("");
#endif

#ifdef LOG
    for (int i = 0; i < 13; i++) {
      dataFile.print(out[i]);
      if (i < 12) {
        dataFile.print(",");
      }
    }
    dataFile.println("");
#endif
  }
#ifdef LOG
  dataFile.close();
#endif
}

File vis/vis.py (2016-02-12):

#!/usr/bin/python3
# -*- coding: utf-8 -*-

import time
import threading
import serial
import cairo
import gi
gi.require_version('Gtk', '3.0')
from gi.repository import Gtk
from gi.repository import GLib

class LivePlot(Gtk.Window):

    def __init__(self):
        Gtk.Window.__init__(self, title="LivePlot")

        self.raw = serial.Serial("/dev/ttyACM0",115200, rtscts=1)
        self.raw.close()
        self.raw.rts = 0
        self.raw.dtr = 0
        self.raw.open()

        self.connect('destroy', lambda w: Gtk.main_quit())
        self.set_default_size(1920, 1080)

        self.drawingarea = Gtk.DrawingArea()
        self.add(self.drawingarea)
        self.drawingarea.connect('draw', self.draw)

        self.show_all()

        GLib.timeout_add(1, self.queue)

    def queue(self):
        self.drawingarea.queue_draw_area(0, 0, 1920, 1080)
        return True

    def draw(self, widget, context):

        try:
            x, y, z = [float(var) for var in str(self.raw.readline()).split(', ')[1:4]]
            w, h = self.get_size()

            sc = (h/2)*0.9

            context.translate(w/2, h/2)
            context.set_line_cap(cairo.LINE_CAP_ROUND)

            # coordinate system
            context.set_line_width(5)
            context.set_source_rgb(0.129, 0.129, 0.129)

            # x
            context.move_to(0, 0)
            context.line_to(-0.87*sc, 0.50*sc)
            context.stroke()
            # y
            context.move_to(0, 0)
            context.line_to(0, 1*sc)
            context.stroke()
            # z
            context.move_to(0, 0)
            context.line_to(0.87*sc, 0.50*sc)
            context.stroke()

            # bars
            context.set_line_width(5)
            context.set_source_rgb(1, 0.341, 0.133)
            # x
            context.move_to(0, 0)
            context.line_to(0.87*y*sc, 0.50*-y*sc)
            context.stroke()
            # y
            context.move_to(0, 0)
            context.line_to(0, 1*z*sc)
            context.stroke()
            # z
            context.move_to(0, 0)
            context.line_to(0.87*x*sc, 0.50*x*sc)
            context.stroke()

        except:
            pass

if __name__ == '__main__':
    plot = LivePlot()
    Gtk.main()

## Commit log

2016-01-21 added v0.2
    [10DOF_FeatherWing.brd, 10DOF_FeatherWing.sch, Feather10DOF.brd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]
2016-01-21 removed files from root dir
    [Feather10DOF.brd, Feather10DOF.sch]
2016-01-22 updatet v2 with more servo headers, better routing
    [10DOF_FeatherWing.brd, 10DOF_FeatherWing.sch]
2016-01-23 added SPI header
    [10DOF_FeatherWing.brd, 10DOF_FeatherWing.sch]
2016-07-11 add v4
    [10DOF_FeatherWing.GBL, 10DOF_FeatherWing.GBO, 10DOF_FeatherWing.GBP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]
2016-09-08 added v5 SenseWing
    [10DOF_FeatherWing.GBL, 10DOF_FeatherWing.GBO, 10DOF_FeatherWing.GBP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]

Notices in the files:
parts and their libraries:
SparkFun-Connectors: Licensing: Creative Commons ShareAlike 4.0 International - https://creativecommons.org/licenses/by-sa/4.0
